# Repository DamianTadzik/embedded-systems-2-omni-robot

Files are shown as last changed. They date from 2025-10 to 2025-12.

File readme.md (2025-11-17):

Hello this is repo for laboratories

Embedded Systems 2 na upelu - ES2_2025

## Project Overview
The project is divided into several software layers, each with a well-defined interface.  
Main goals:
- Controlling the robot via a wireless controller.
- Training a neural network to detect specific objects (in this project: a can of Monster).
- Creating a program that makes the robot drive to a certain object and keep a desired distance.
- Designing and 3D printing accessories (camera station, battery station).

---

## Software Architecture

### L1 — Motion Control Layer
The main task of this layer is controlling the robot via signals directed to the wheels.  
- Receives the control vector **[Vx Vy ω]**, where:
  - Vx, Vy are linear velocities in m/s
  - ω is the angular velocity in rad/s
- This layer runs in a loop. If there is no message on the MQTT topic, the motors are stopped.
- Listens to MQTT topic for control commands.

---

### L2 — Control and Integration Layer
Layer 2 connects Layer 1 and Layer 3.  
- Implements the PID controller to control the robot’s speed and angle of its path.
- Maintains the robot at the desired distance from the object.
- Passes processed control signals to L1.

---

### L3 — Perception Layer
This layer implements the neural network (YOLO) to detect cans.  
- The Hisense camera used in the project provides depth calculation, which is passed to L2.
- The dataset consists of both self-collected and external images:
  - 30 self-collected and annotated images.
  - Additional images sourced from the internet and re-annotated to match labeling standards.

Dataset link: [Monster Net on Roboflow](https://universe.roboflow.com/monster-nzhgs/monster_net-e7vd2)

---

## System Flow
1. Neural network detects the can and outputs position and distance (L3)  
2. PID controller processes this data (L2)  
3. Control vector [Vx Vy ω] is sent to the robot motors (L1)  
4. Robot moves toward the object and maintains distance

---

## Hardware and Accessories
- 3D printed camera station
- 3D printed battery station
- Designed to improve stability and functionality of the robot

---

## Task Allocation

| Name | Responsibility | Layer |
|---|---|---|
| Damian Brzana | L1, remote controller, system architecture, LL Arduino driver | L1 |
| Oskar Brandys | L2 | L2 |
| Janusz Pawlicki | accessories, neural network | L3 |
| Adrian Paś | accessories, L2 | L2 |
| Stanisław Olech | neural network | L3 |

---

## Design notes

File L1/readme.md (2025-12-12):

# L1 – High-Level Velocity & Wheel Speed Control

The **L1 layer** is responsible for closing the **wheel speed control loop** on the host computer (Jetson/PC).
It receives high-level velocity commands `(vx, vy, omega)`, converts them into **desired wheel angular speeds**, and **regulates each wheel using PID controllers** based on encoder feedback from the LL (Arduino) layer.

L1 therefore no longer operates in open-loop PWM mode – **wheel speed control is closed in L1**.

---

## Responsibilities of L1

* Receive high-level velocity commands `(vx, vy, omega)` via MQTT
* Compute desired wheel angular velocities using mecanum inverse kinematics
* Read encoder feedback from LL over UART
* Compute wheel angular speeds `[rad/s]`
* Run **4 independent PID controllers** (one per wheel)
* Send **PWM duty cycles** to LL

---

## Control Architecture

```
(vx, vy, omega)
        ↓
   Inverse Kinematics
        ↓
Desired wheel speeds [rad/s]
        ↓
   PID (per wheel)
        ↓
   PWM duty cycles
        ↓
        LL (Arduino)
        ↓
     Motors + Encoders
        ↑
   Encoder feedback (UART)
```

---

## Project Structure

```
L1.py              # Main control loop (IK + PID + UART)
PID.py             # Simple PID controller implementation
kinematics.py      # Mecanum inverse kinematics
serial_link.py     # UART protocol + encoder decoding
mqtt_client.py     # MQTT interface (cmd_vel)
app.html           # Web joystick (debug / teleop)
TODO.md            # Planned improvements
```

---

## MQTT Interface

### Topic

```
robot/cmd_vel
```

### Message format

```json
{ "vx": 0.0, "vy": 0.0, "omega": 0.0 }
```

* `vx`, `vy` – linear velocities [m/s]
* `omega` – angular velocity [rad/s]

Commands may originate from:

* **L2 motion planner** (normal operation)
* **Web UI** (`app.html`) for testing

---

## UART Interface (L1 ↔ LL)

### L1 → LL

* Sends PWM duty cycles for 4 wheels
* Range: `[-127, 127]` (mapped internally to signed percentage)

### LL → L1

* Sends raw encoder counts (16-bit, with wrap-around)
* L1 computes:

  * wheel angular speed `[rad/s]`
  * loop `dt`

All encoder handling and speed estimation is done in **serial_link.py**.

---

## PID Control

* One PID per wheel: `TL`, `TR`, `BL`, `BR`
* Inputs:

  * Target wheel speed `[rad/s]`
  * Measured wheel speed `[rad/s]`
* Output:

  * PWM duty cycle command

Current gains (to be tuned):

```
kp = 1.2
ki = 12.0
kd = 0.04
output_limit = 127
```

---

## Web Controller (Debug Only)

`app.html` provides:

* Virtual joystick → `(vx, vy)`
* Slider → `omega`
* MQTT over WebSockets

Used **only for debugging and teleoperation** when L2 is unavailable.

---

## How to Run

### 1. Start MQTT broker

```
mosquitto -v -c my_mosquitto.conf
```

### 2. Run L1

```
python3 L1.py
```

Dependencies:

```
pip install paho-mqtt pyserial numpy
```

L1 will:

* Connect to MQTT (`localhost:1883`)
* Open `/dev/ttyACM0`
* Start encoder reader thread
* Close the wheel speed control loop

---

## Data Flow Summary

```
L2 / Web UI
      ↓ MQTT
     L1 (IK + PID)
      ↓ UART
     LL (Motor driver)
      ↓
    Motors
```

---

## Notes

* L1 is now a **real-time wheel speed regulator**, not just a kinematics bridge
* LL firmware is simplified (no PID inside Arduino)
* Timing quality depends on host OS scheduling
* Future improvement: move PID to LL if hard real-time is required

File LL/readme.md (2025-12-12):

# LL – Low-Level Motor & Encoder Interface

The **LL layer** runs on the Arduino and acts as a **pure hardware interface**.
It applies motor commands and reports encoder data. **No control logic is implemented here.**

---

## Responsibilities

* Receive PWM duty cycle commands from L1 over UART
* Drive motor direction and PWM outputs
* Read quadrature encoders
* Send **raw 16-bit encoder counts** back to L1

---

## Explicitly NOT in LL

* No PID or control loops
* No kinematics
* No velocity regulation
* No decision logic

All control is handled in **L1**.

---

## UART Interface

### L1 → LL (Motor command frame)

```
[START][TL][TR][BL][BR][CHECKSUM]
```

* Signed values encode direction and duty cycle

### LL → L1 (Encoder frame)

```
[START][TL_lo][TL_hi][TR_lo][TR_hi][BL_lo][BL_hi][BR_lo][BR_hi][CHECKSUM]
```

* 16-bit encoder counts
* Wrap-around handled in L1

---

## Timing

* LL runs as fast as possible
* No blocking delays
* Control timing is dictated by L1

---

## Notes

LL is intentionally minimal. If behavior is incorrect, the issue is almost certainly in **L1**, not LL.

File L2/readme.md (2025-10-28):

L2- Second layer

Responsible for controling velocities of the robot's frame of reference based on the distance from detected object from the robot and on location of it's center in the frame.

INPUTS:

&nbsp;	- Distance from the detected object (distance)

&nbsp;	- Location of center of detected object in the frame (C(x,y))

OUTPUTS:

&nbsp;	- vx - translational velocity along x axis of robot's reference frame

&nbsp;	- vy - translational velocity along y axis of robot's reference frame

&nbsp;	- omega - rotational velocity along z axis of robot's reference frame

Script consists of angle and distance regulators (which are implemented, based on choice, with two-state position controllers or PID controllers), which operate on angle and distance variables. Both are calculated with help of inputs and knwoledge of camera's FOV.

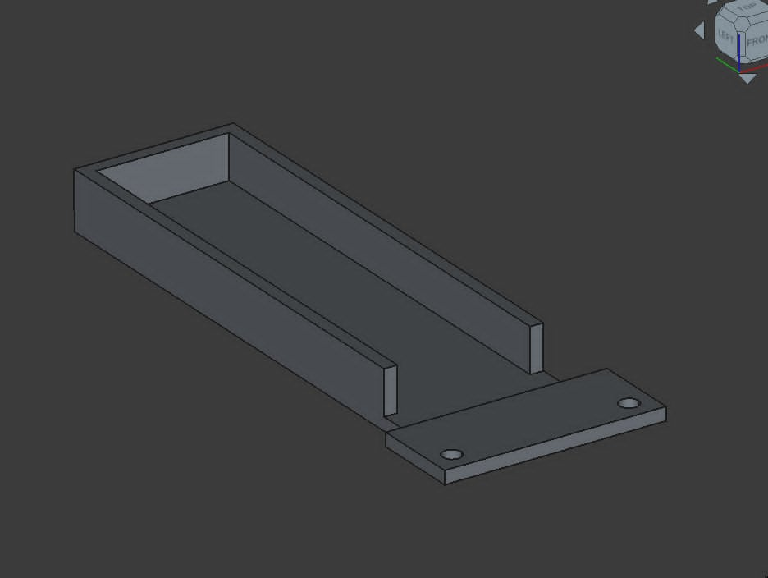
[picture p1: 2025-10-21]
Hardware/bateria.jpg

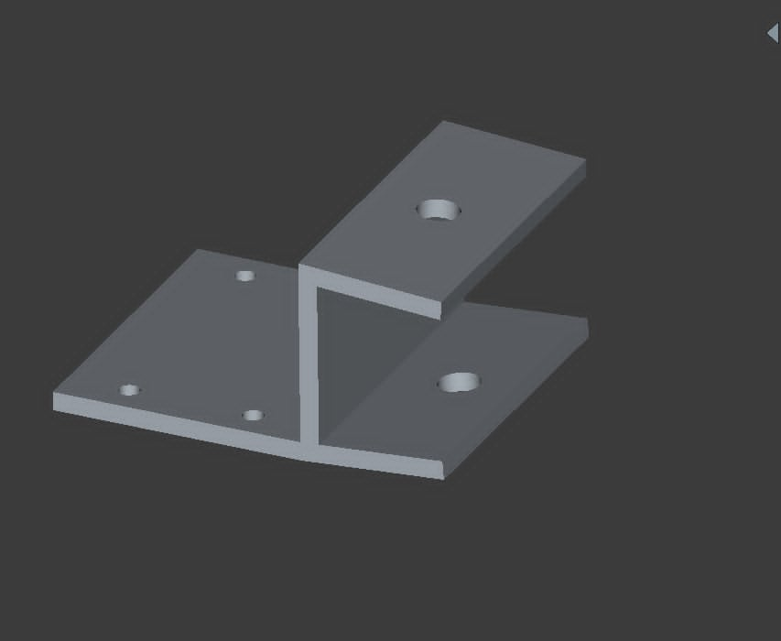
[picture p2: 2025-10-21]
Hardware/kamera.jpg

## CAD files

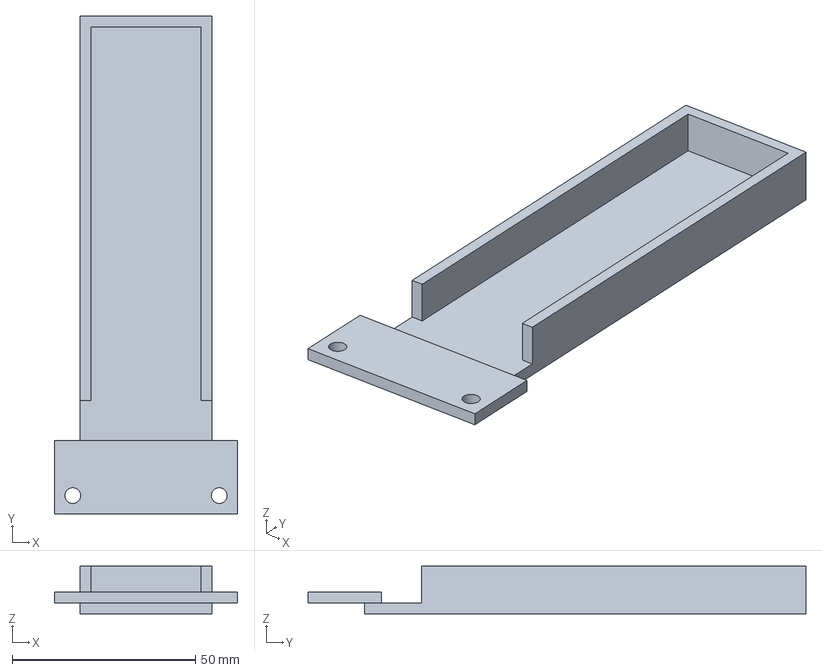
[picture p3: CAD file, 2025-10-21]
Hardware/trzymacz_baterii.FCStd
50.0 x 136.0 x 13.0 mm

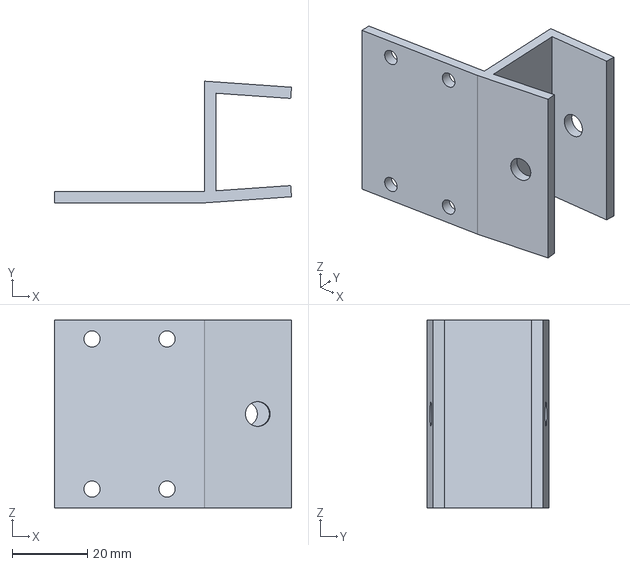
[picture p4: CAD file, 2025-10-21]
Hardware/uchwyt_na_kamere.FCStd
63.2 x 32.4 x 50.0 mm

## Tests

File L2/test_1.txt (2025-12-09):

est_angle: 0.0est_dist: 0.3speeds: 0,0detection_flag: Falseraw_angle: Noneest_angle: 0.0est_dist: 0.3speeds: 0,0detection_flag: Falseraw_angle: Noneest_angle: 0.0est_dist: 0.3speeds: 0,0detection_flag: Falseraw_angle: Noneraw_dist: None
est_angle: 0.0est_dist: 0.3speeds: 0,0detection_flag: Falseraw_angle: Noneraw_dist: None
est_angle: 0.0est_dist: 0.3speeds: 0,0detection_flag: Falseraw_angle: Noneraw_dist: None
est_angle: 0.0est_dist: 0.3speeds: 0,0detection_flag: Falseraw_angle: Noneraw_dist: None
est_angle: 0.0est_dist: 0.3speeds: 0,0detection_flag: Falseraw_angle: Noneraw_dist: None
est_angle: 0.0est_dist: 0.3speeds: 0,0detection_flag: Falseraw_angle: Noneraw_dist: None
est_angle: 0.0est_dist: 0.3speeds: 0,0detection_flag: Falseraw_angle: Noneraw_dist: None
est_angle: 0.0est_dist: 0.3speeds: 0,0detection_flag: Falseraw_angle: Noneraw_dist: None
est_angle: 0.0est_dist: 0.3speeds: 0,0detection_flag: Falseraw_angle: Noneraw_dist: None
est_angle: 0.0est_dist: 0.3speeds: 0,0detection_flag: Falseraw_angle: Noneraw_dist: None
est_angle: 0.0est_dist: 0.3speeds: 0,0detection_flag: Falseraw_angle: Noneraw_dist: None
est_angle: 0.0est_dist: 0.3speeds: 0,0detection_flag: Falseraw_angle: Noneraw_dist: None
est_angle: 0.0est_dist: 0.3speeds: 0,0detection_flag: Falseraw_angle: Noneraw_dist: None
est_angle: 0.0est_dist: 0.3speeds: 0,0detection_flag: Falseraw_angle: Noneraw_dist: None
est_angle: 0.0est_dist: 0.3speeds: 0,0detection_flag: Falseraw_angle: Noneraw_dist: None
est_angle: 0.0est_dist: 0.3speeds: 0,0detection_flag: Falseraw_angle: Noneraw_dist: None
est_angle: 0.0est_dist: 0.3speeds: 0,0detection_flag: Falseraw_angle: Noneraw_dist: None
est_angle: 0.0est_dist: 0.3speeds: 0,0detection_flag: Falseraw_angle: Noneraw_dist: None
est_angle: 0.0est_dist: 0.3speeds: 0,0detection_flag: Falseraw_angle: Noneraw_dist: None
est_angle: 0.0est_dist: 0.3speeds: 0,0detection_flag: Falseraw_angle: Noneraw_dist: None
est_angle: 0.0est_dist: 0.3speeds: 0,0detection_flag: Falseraw_angle: Noneraw_dist: None
est_angle: 0.0est_dist: 0.3speeds: 0,0detection_flag: Falseraw_angle: Noneraw_dist: None
est_angle: 0.0est_dist: 0.3speeds: 0,0detection_flag: Falseraw_angle: Noneraw_dist: None
est_angle: 0.0est_dist: 0.3speeds: 0,0detection_flag: Falseraw_angle: Noneraw_dist: None
est_angle: 0.0est_dist: 0.3speeds: 0,0detection_flag: Falseraw_angle: Noneraw_dist: None
est_angle: 0.0est_dist: 0.3speeds: 0,0detection_flag: Falseraw_angle: Noneraw_dist: None
est_angle: 0.0est_dist: 0.3speeds: 0,0detection_flag: Falseraw_angle: Noneraw_dist: None
est_angle: 0.0est_dist: 0.3speeds: 0,0detection_flag: Falseraw_angle: Noneraw_dist: None
est_angle: 0.0est_dist: 0.3speeds: 0,0detection_flag: Falseraw_angle: Noneraw_dist: None
est_angle: 0.0est_dist: 0.3speeds: 0,0detection_flag: Falseraw_angle: Noneraw_dist: None
est_angle: 0.0est_dist: 0.3speeds: 0,0detection_flag: Falseraw_angle: Noneraw_dist: None
est_angle: 0.0est_dist: 0.3speeds: 0,0detection_flag: Falseraw_angle: Noneraw_dist: None
est_angle: 0.0est_dist: 0.3speeds: 0,0detection_flag: Falseraw_angle: Noneraw_dist: None
est_angle: 0.0est_dist: 0.3speeds: 0,0detection_flag: Falseraw_angle: Noneraw_dist: None
est_angle: 0.0est_dist: 0.3speeds: 0,0detection_flag: Falseraw_angle: Noneraw_dist: None
est_angle: 0.0est_dist: 0.3speeds: 0,0detection_flag: Falseraw_angle: Noneraw_dist: None
est_angle: 0.0est_dist: 0.3speeds: 0,0detection_flag: Falseraw_angle: Noneraw_dist: None
est_angle: 0.0est_dist: 0.3speeds: 0,0detection_flag: Falseraw_angle: Noneraw_dist: None
est_angle: 0.0est_dist: 0.3speeds: 0,0detection_flag: Falseraw_angle: Noneraw_dist: None
est_angle: 0.0est_dist: 0.3speeds: 0,0detection_flag: Falseraw_angle: Noneraw_dist: None
est_angle: 0.0est_dist: 0.3speeds: 0,0detection_flag: Falseraw_angle: Noneraw_dist: None
est_angle: 0.0est_dist: 0.3speeds: 0,0detection_flag: Falseraw_angle: Noneraw_dist: None
est_angle: 0.0est_dist: 0.3speeds: 0,0detection_flag: Falseraw_angle: Noneraw_dist: None
est_angle: 0.0est_dist: 0.3speeds: 0,0detection_flag: Falseraw_angle: Noneraw_dist: None
est_angle: 0.0est_dist: 0.3speeds: 0,0detection_flag: Falseraw_angle: Noneraw_dist: None
est_angle: 0.0est_dist: 0.3speeds: 0,0detection_flag: Falseraw_angle: Noneraw_dist: None
est_angle: 0.0est_dist: 0.3speeds: 0,0detection_flag: Falseraw_angle: Noneraw_dist: None
est_angle: 0.0est_dist: 0.3speeds: 0,0detection_flag: Falseraw_angle: Noneraw_dist: None
est_angle: 0.0est_dist: 0.3speeds: 0,0detection_flag: Falseraw_angle: Noneraw_dist: None
est_angle: 0.0est_dist: 0.3speeds: 0,0detection_flag: Falseraw_angle: Noneraw_dist: None
est_angle: 0.0est_dist: 0.3speeds: 0,0detection_flag: Falseraw_angle: Noneraw_dist: None
est_angle: 0.0est_dist: 0.3speeds: 0,0detection_flag: Falseraw_angle: Noneraw_dist: None
est_angle: 0.0est_dist: 0.3speeds: 0,0detection_flag: Falseraw_angle: Noneraw_dist: None
est_angle: 0.0est_dist: 0.3speeds: 0,0detection_flag: Falseraw_angle: Noneraw_dist: None
est_angle: 0.0est_dist: 0.3speeds: 0,0detection_flag: Falseraw_angle: Noneraw_dist: None
est_angle: 0.0est_dist: 0.3speeds: 0,0detection_flag: Falseraw_angle: Noneraw_dist: None
est_angle: 0.0est_dist: 0.3speeds: 0,0detection_flag: Falseraw_angle: Noneraw_dist: None
est_angle: 0.0est_dist: 0.3speeds: 0,0detection_flag: Falseraw_angle: Noneraw_dist: None
est_angle: 0.0est_dist: 0.3speeds: 0,0detection_flag: Falseraw_angle: Noneraw_dist: None
est_angle: 0.0est_dist: 0.3speeds: 0,0detection_flag: Falseraw_angle: Noneraw_dist: None
est_angle: 0.0est_dist: 0.3speeds: 0,0detection_flag: Falseraw_angle: Noneraw_dist: None
est_angle: 0.0est_dist: 0.3speeds: 0,0detection_flag: Falseraw_angle: Noneraw_dist: None
est_angle: 0.0est_dist: 0.3speeds: 0,0detection_flag: Falseraw_angle: Noneraw_dist: None
est_angle: 0.0est_dist: 0.3speeds: 0,0detection_flag: Falseraw_angle: Noneraw_dist: None
est_angle: 0.0est_dist: 0.3speeds: 0,0detection_flag: Falseraw_angle: Noneraw_dist: None
est_angle: 0.0est_dist: 0.3speeds: 0,0detection_flag: Falseraw_angle: Noneraw_dist: None
est_angle: 0.0est_dist: 0.3speeds: 0,0detection_flag: Falseraw_angle: Noneraw_dist: None
est_angle: 0.0est_dist: 0.3speeds: 0,0detection_flag: Falseraw_angle: Noneraw_dist: None
est_angle: 0.0est_dist: 0.3speeds: 0,0detection_flag: Falseraw_angle: Noneraw_dist: None
est_angle: 0.0est_dist: 0.3speeds: 0,0detection_flag: Falseraw_angle: Noneraw_dist: None
est_angle: 0.0est_dist: 0.3speeds: 0,0detection_flag: Falseraw_angle: Noneraw_dist: None
est_angle: 0.0est_dist: 0.3speeds: 0,0detection_flag: Falseraw_angle: Noneraw_dist: None
est_angle: 0.0est_dist: 0.3speeds: 0,0detection_flag: Falseraw_angle: Noneraw_dist: None
est_angle: 0.0est_dist: 0.3speeds: 0,0detection_flag: Falseraw_angle: Noneraw_dist: None
est_angle: 0.0est_dist: 0.3speeds: 0,0detection_flag: Falseraw_angle: Noneraw_dist: None
est_angle: 0.0est_dist: 0.3speeds: 0,0detection_flag: Falseraw_angle: Noneraw_dist: None
est_angle: 0.0est_dist: 0.3speeds: 0,0detection_flag: Falseraw_angle: Noneraw_dist: None
est_angle: 0.0est_dist: 0.3speeds: 0,0detection_flag: Falseraw_angle: Noneraw_dist: None
est_angle: 0.0est_dist: 0.3speeds: 0,0detection_flag: Falseraw_angle: Noneraw_dist: None
est_angle: 0.0est_dist: 0.3speeds: 0,0detection_flag: Falseraw_angle: Noneraw_dist: None
est_angle: 0.0est_dist: 0.3speeds: 0,0detection_flag: Falseraw_angle: Noneraw_dist: None
est_angle: 0.0est_dist: 0.3speeds: 0,0detection_flag: Falseraw_angle: Noneraw_dist: None
est_angle: 0.0est_dist: 0.3speeds: 0,0detection_flag: Falseraw_angle: Noneraw_dist: None
est_angle: 0.0est_dist: 0.3speeds: 0,0detection_flag: Falseraw_angle: Noneraw_dist: None
est_angle: 0.0est_dist: 0.3speeds: 0,0detection_flag: Falseraw_angle: Noneraw_dist: None
est_angle: 0.0est_dist: 0.3speeds: 0,0detection_flag: Falseraw_angle: Noneraw_dist: None
est_angle: 0.0est_dist: 0.3speeds: 0,0detection_flag: Falseraw_angle: Noneraw_dist: None
est_angle: 0.0est_dist: 0.3speeds: 0,0detection_flag: Falseraw_angle: Noneraw_dist: None
est_angle: 0.0est_dist: 0.3speeds: 0,0detection_flag: Falseraw_angle: Noneraw_dist: None
est_angle: 0.0est_dist: 0.3speeds: 0,0detection_flag: Falseraw_angle: Noneraw_dist: None
est_angle: 0.0est_dist: 0.3speeds: 0,0detection_flag: Falseraw_angle: Noneraw_dist: None
est_angle: 0.0est_dist: 0.3speeds: 0,0detection_flag: Falseraw_angle: Noneraw_dist: None
est_angle: 0.0est_dist: 0.3speeds: 0,0detection_flag: Falseraw_angle: Noneraw_dist: None
est_angle: 0.0est_dist: 0.3speeds: 0,0detection_flag: Falseraw_angle: Noneraw_dist: None
est_angle: 0.0est_dist: 0.3speeds: 0,0detection_flag: Falseraw_angle: Noneraw_dist: None
est_angle: 0.0est_dist: 0.3speeds: 0,0detection_flag: Falseraw_angle: Noneraw_dist: None
est_angle: 0.0est_dist: 0.3speeds: 0,0detection_flag: Falseraw_angle: Noneraw_dist: None
est_angle: 0.0est_dist: 0.3speeds: 0,0detection_flag: Falseraw_angle: Noneraw_dist: None
est_angle: 0.0est_dist: 0.3speeds: 0,0detection_flag: Falseraw_angle: Noneraw_dist: None
est_angle: 0.0est_dist: 0.3speeds: 0,0detection_flag: Trueraw_angle: Noneraw_dist: None
est_angle: 0.0est_dist: 0.3299961805343628speeds: 0.3,0.0detection_flag: Falseraw_angle: Noneraw_dist: None
est_angle: 0.0est_dist: 0.3630041069022809speeds: 0.3299961805343628,0.0detection_flag: Falseraw_angle: Noneraw_dist: None
est_angle: 0.0est_dist: 0.3680074638358747speeds: 0.05,0.0detection_flag: Falseraw_angle: Noneraw_dist: None
est_angle: 0.0est_dist: 0.3730068987838422speeds: 0.05,0.0detection_flag: Falseraw_angle: Noneraw_dist: None
est_angle: 0.0est_dist: 0.37800774040142643speeds: 0.05,0.0detection_flag: Trueraw_angle: Noneraw_dist: None
est_angle: 0.0est_dist: 0.38301033439556703speeds: 0.05,0.0detection_flag: Falseraw_angle: Noneraw_dist: None
est_angle: 0.0est_dist: 0.38801023425976383speeds: 0.05,0.0detection_flag: Falseraw_angle: Noneraw_dist: None
est_angle: 0.0est_dist: 0.39301180305401434speeds: 0.05,0.0detection_flag: Falseraw_angle: Noneraw_dist: None
est_angle: 0.0est_dist: 0.3980129784576093speeds: 0.05,0.0detection_flag: Falseraw_angle: Noneraw_dist: None
est_angle: 0.0est_dist: 0.40301396312634097speeds: 0.05,0.0detection_flag: Falseraw_angle: Noneraw_dist: None
est_angle: 0.0est_dist: 0.4080159968368207speeds: 0.05,0.0detection_flag: Falseraw_angle: Noneraw_dist: None
est_angle: 0.0est_dist: 0.4130165285102521speeds: 0.05,0.0detection_flag: Falseraw_angle: Noneraw_dist: None
est_angle: 0.0est_dist: 0.4180184191695844speeds: 0.05,0.0detection_flag: Falseraw_angle: Noneraw_dist: None
est_angle: 0.0est_dist: 0.42301829519192324speeds: 0.05,0.0detection_flag: Trueraw_angle: Noneraw_dist: None
est_angle: 0.0est_dist: 0.42801850500027283speeds: 0.05,0.0detection_flag: Falseraw_angle: Noneraw_dist: None
est_angle: 0.0est_dist: 0.43301983537594424speeds: 0.05,0.0detection_flag: Falseraw_angle: Noneraw_dist: None
est_angle: 0.0est_dist: 0.4380209034911786speeds: 0.05,0.0detection_flag: Falseraw_angle: Noneraw_dist: None
est_angle: 0.0est_dist: 0.4430216258994733speeds: 0.05,0.0detection_flag: Falseraw_angle: Noneraw_dist: None
est_angle: 0.0est_dist: 0.4480245179168378speeds: 0.05,0.0detection_flag: Falseraw_angle: Noneraw_dist: None
est_angle: 0.0est_dist: 0.4530239290229474speeds: 0.05,0.0detection_flag: Falseraw_angle: Noneraw_dist: None
est_angle: 0.0est_dist: 0.45802496137539495speeds: 0.05,0.0detection_flag: Falseraw_angle: Noneraw_dist: None
est_angle: 0.0est_dist: 0.46302591028133977speeds: 0.05,0.0detection_flag: Falseraw_angle: Noneraw_dist: None
est_angle: 0.0est_dist: 0.4680267757407819speeds: 0.05,0.0detection_flag: Trueraw_angle: Noneraw_dist: None
est_angle: 0.0est_dist: 0.47302789153973207speeds: 0.05,0.0detection_flag: Falseraw_angle: Noneraw_dist: None
est_angle: 0.0est_dist: 0.4780290192596112speeds: 0.05,0.0detection_flag: Falseraw_angle: Noneraw_dist: None
est_angle: 0.0est_dist: 0.48303152980724917speeds: 0.05,0.0detection_flag: Falseraw_angle: Noneraw_dist: None
est_angle: 0.0est_dist: 0.4880309885970746speeds: 0.05,0.0detection_flag: Falseraw_angle: Noneraw_dist: None
est_angle: 0.0est_dist: 0.493032056712309speeds: 0.05,0.0detection_flag: Falseraw_angle: Noneraw_dist: None
est_angle: 0.0est_dist: 0.4980329221717511speeds: 0.05,0.0detection_flag: Falseraw_angle: Noneraw_dist: None
est_angle: 0.0est_dist: 0.5030336445800457speeds: 0.05,0.0detection_flag: Falseraw_angle: Noneraw_dist: None
est_angle: 0.0est_dist: 0.5080350822440777speeds: 0.05,0.0detection_flag: Falseraw_angle: Noneraw_dist: None
est_angle: 0.0est_dist: 0.5130349821082745speeds: 0.05,0.0detection_flag: Trueraw_angle: Noneraw_dist: None
est_angle: 0.0est_dist: 0.5180367535583172speeds: 0.05,0.0detection_flag: Falseraw_angle: Noneraw_dist: None
est_angle: 0.0est_dist: 0.5230373329154645speeds: 0.05,0.0detection_flag: Falseraw_angle: Noneraw_dist: None
est_angle: 0.0est_dist: 0.5280379957191144speeds: 0.05,0.0detection_flag: Falseraw_angle: Noneraw_dist: None
est_angle: 0.0est_dist: 0.5330392307273542speeds: 0.05,0.0detection_flag: Falseraw_angle: Noneraw_dist: None
est_angle: 0.0est_dist: 0.5380401319495831speeds: 0.05,0.0detection_flag: Falseraw_angle: Noneraw_dist: None
est_angle: 0.0est_dist: 0.5430424398414289speeds: 0.05,0.0detection_flag: Falseraw_angle: Noneraw_dist: None
est_angle: 0.0est_dist: 0.5480425781242048speeds: 0.05,0.0detection_flag: Falseraw_angle: Noneraw_dist: None
est_angle: 0.0est_dist: 0.5530432766906416speeds: 0.05,0.0detection_flag: Falseraw_angle: Noneraw_dist: None
est_angle: 0.0est_dist: 0.5580442613593732speeds: 0.05,0.0detection_flag: Falseraw_angle: Noneraw_dist: None
est_angle: 0.0est_dist: 0.5630447453490888speeds: 0.05,0.0detection_flag: Trueraw_angle: Noneraw_dist: None
est_angle: 0.0est_dist: 0.5680453723899518speeds: 0.05,0.0detection_flag: Falseraw_angle: Noneraw_dist: None
est_angle: 0.0est_dist: 0.5730460351936016speeds: 0.05,0.0detection_flag: Falseraw_angle: Noneraw_dist: None
est_angle: 0.0est_dist: 0.5780467933646832speeds: 0.05,0.0detection_flag: Falseraw_angle: Noneraw_dist: None
est_angle: 0.0est_dist: 0.5830476230613385speeds: 0.05,0.0detection_flag: Falseraw_angle: Noneraw_dist: None
est_angle: 0.0est_dist: 0.5880482024184858speeds: 0.05,0.0detection_flag: Falseraw_angle: Noneraw_dist: None
est_angle: 0.0est_dist: 0.5930486029616987speeds: 0.05,0.0detection_flag: Falseraw_angle: Noneraw_dist: None
est_angle: 0.0est_dist: 0.5980495041839277speeds: 0.05,0.0detection_flag: Falseraw_angle: Noneraw_dist: None
est_angle: 0.0est_dist: 0.6030502027503645speeds: 0.05,0.0detection_flag: Falseraw_angle: Noneraw_dist: None
est_angle: 0.0est_dist: 0.6080513662330305speeds: 0.05,0.0detection_flag: Trueraw_angle: Noneraw_dist: None
est_angle: 0.0est_dist: 0.6130523389808332speeds: 0.05,0.0detection_flag: Falseraw_angle: Noneraw_dist: None
est_angle: 0.0est_dist: 0.6180546826354658speeds: 0.05,0.0detection_flag: Falseraw_angle: Noneraw_dist: None
est_angle: 0.0est_dist: 0.623053426169554speeds: 0.05,0.0detection_flag: Falseraw_angle: Noneraw_dist: None
est_angle: 0.0est_dist: 0.6280537909499799speeds: 0.05,0.0detection_flag: Falseraw_angle: Noneraw_dist: None
est_angle: 0.0est_dist: 0.6330545848838484speeds: 0.05,0.0detection_flag: Falseraw_angle: Noneraw_dist: None
est_angle: 0.0est_dist: 0.6380568331710493speeds: 0.05,0.0detection_flag: Falseraw_angle: Noneraw_dist: None
est_angle: 0.0est_dist: 0.6430568045608198speeds: 0.05,0.0detection_flag: Falseraw_angle: Noneraw_dist: None
est_angle: 0.0est_dist: 0.648057681941191speeds: 0.05,0.0detection_flag: Falseraw_angle: Noneraw_dist: None
est_angle: 0.0est_dist: 0.6530577010146773speeds: 0.05,0.0detection_flag: Trueraw_angle: Noneraw_dist: None
est_angle: 0.0est_dist: 0.6580583518973983speeds: 0.05,0.0detection_flag: Falseraw_angle: Noneraw_dist: None
est_angle: 0.0est_dist: 0.6630593842498458speeds: 0.05,0.0detection_flag: Falseraw_angle: Noneraw_dist: None
est_angle: 0.0est_dist: 0.6680612391463912speeds: 0.05,0.0detection_flag: Falseraw_angle: Noneraw_dist: None
est_angle: 0.0est_dist: 0.6730602926246321speeds: 0.05,0.0detection_flag: Falseraw_angle: Noneraw_dist: None
est_angle: 0.0est_dist: 0.6780612772933637speeds: 0.05,0.0detection_flag: Falseraw_angle: Noneraw_dist: None
est_angle: 0.0est_dist: 0.6830619043342268speeds: 0.05,0.0detection_flag: Falseraw_angle: Noneraw_dist: None
est_angle: 0.0est_dist: 0.688062483691374speeds: 0.05,0.0detection_flag: Falseraw_angle: Noneraw_dist: None
est_angle: 0.0est_dist: 0.693063921355406speeds: 0.05,0.0detection_flag: Falseraw_angle: Noneraw_dist: None
est_angle: 0.0est_dist: 0.6980651802055036speeds: 0.05,0.0detection_flag: Falseraw_angle: Noneraw_dist: None
est_angle: 0.0est_dist: 0.7030660814277325speeds: 0.05,0.0detection_flag: Trueraw_angle: Noneraw_dist: None
est_angle: 0.0est_dist: 0.7080672449103985speeds: 0.05,0.0detection_flag: Falseraw_angle: Noneraw_dist: None
est_angle: 0.0est_dist: 0.7130684918395672speeds: 0.05,0.0detection_flag: Falseraw_angle: Noneraw_dist: None
est_angle: 0.0est_dist: 0.7180688566199932speeds: 0.05,0.0detection_flag: Falseraw_angle: Noneraw_dist: None
est_angle: 0.0est_dist: 0.7230711764327679speeds: 0.05,0.0detection_flag: Falseraw_angle: Noneraw_dist: None
est_angle: 0.0est_dist: 0.7280720061294231speeds: 0.05,0.0detection_flag: Falseraw_angle: Noneraw_dist: None
est_angle: 0.0est_dist: 0.7330717629424724speeds: 0.05,0.0detection_flag: Falseraw_angle: Noneraw_dist: None
est_angle: 0.0est_dist: 0.7380729025832805speeds: 0.05,0.0detection_flag: Falseraw_angle: Noneraw_dist: None
est_angle: 0.0est_dist: 0.7430760091773662speeds: 0.05,0.0detection_flag: Falseraw_angle: Noneraw_dist: None
est_angle: 0.0est_dist: 0.7480761116973552speeds: 0.05,0.0detection_flag: Trueraw_angle: Noneraw_dist: None
est_angle: 0.0est_dist: 0.7530770248405132speeds: 0.05,0.0detection_flag: Falseraw_angle: Noneraw_dist: None
est_angle: 0.0est_dist: 0.7580783075324687speeds: 0.05,0.0detection_flag: Falseraw_angle: Noneraw_dist: None
est_angle: 0.0est_dist: 0.7630793279639873speeds: 0.05,0.0detection_flag: Falseraw_angle: Noneraw_dist: None
est_angle: 0.0est_dist: 0.768080837153593speeds: 0.05,0.0detection_flag: Falseraw_angle: Noneraw_dist: None
est_angle: 0.0est_dist: 0.7730816310874614speeds: 0.05,0.0detection_flag: Falseraw_angle: Noneraw_dist: None
est_angle: 0.0est_dist: 0.778082663439909speeds: 0.05,0.0detection_flag: Falseraw_angle: Noneraw_dist: None
est_angle: 0.0est_dist: 0.7830835765830669speeds: 0.05,0.0detection_flag: Falseraw_angle: Noneraw_dist: None
est_angle: 0.0est_dist: 0.7880849665633831speeds: 0.05,0.0detection_flag: Falseraw_angle: Noneraw_dist: None
est_angle: 0.0est_dist: 0.7930857962600384speeds: 0.05,0.0detection_flag: Trueraw_angle: Noneraw_dist: None
est_angle: 0.0est_dist: 0.7980863517753277speeds: 0.05,0.0detection_flag: Falseraw_angle: Noneraw_dist: None
est_angle: 0.0est_dist: 0.8030869549743328speeds: 0.05,0.0detection_flag: Falseraw_angle: Noneraw_dist: None
est_angle: 0.0est_dist: 0.8080877727500592speeds: 0.05,0.0detection_flag: Falseraw_angle: Noneraw_dist: None
est_angle: 0.0est_dist: 0.8130890792838726speeds: 0.05,0.0detection_flag: Falseraw_angle: Noneraw_dist: None
est_angle: 0.0est_dist: 0.818089861296812speeds: 0.05,0.0detection_flag: Falseraw_angle: Noneraw_dist: None
est_angle: 0.0est_dist: 0.8230909770957623speeds: 0.05,0.0detection_flag: Falseraw_angle: Noneraw_dist: None
est_angle: 0.0est_dist: 0.828092486285368speeds: 0.05,0.0detection_flag: Falseraw_angle: Noneraw_dist: None
est_angle: 0.0est_dist: 0.833103997134367speeds: 0.05,0.0detection_flag: Falseraw_angle: Noneraw_dist: None
est_angle: 0.0est_dist: 0.8381055182449016speeds: 0.05,0.0detection_flag: Falseraw_angle: Noneraw_dist: None
est_angle: 0.0est_dist: 0.8431065267554912speeds: 0.05,0.0detection_flag: Falseraw_angle: Noneraw_dist: None
est_angle: 0.0est_dist: 0.8481074160567913speeds: 0.05,0.0detection_flag: Falseraw_angle: Noneraw_dist: None
est_angle: 0.0est_dist: 0.8531087106696759speeds: 0.05,0.0detection_flag: Falseraw_angle: Noneraw_dist: None
est_angle: 0.0est_dist: 0.8581096476546918speeds: 0.05,0.0detection_flag: Falseraw_angle: Noneraw_dist: None
est_angle: 0.0est_dist: 0.8631108349792157speeds: 0.05,0.0detection_flag: Falseraw_angle: Noneraw_dist: None
est_angle: 0.0est_dist: 0.8681122249595319speeds: 0.05,0.0detection_flag: Falseraw_angle: Noneraw_dist: None
est_angle: 0.0est_dist: 0.8731126851073896speeds: 0.05,0.0detection_flag: Trueraw_angle: Noneraw_dist: None
est_angle: 0.0est_dist: 0.8781152671806013speeds: 0.05,0.0detection_flag: Trueraw_angle: Noneraw_dist: None
est_angle: 0.0est_dist: 0.88311571540753speeds: 0.05,0.0detection_flag: Falseraw_angle: Noneraw_dist: None
est_angle: 0.0est_dist: 0.8881165689460432speeds: 0.05,0.0detection_flag: Falseraw_angle: Noneraw_dist: None
est_angle: 0.0est_dist: 0.8931176609031355speeds: 0.05,0.0detection_flag: Falseraw_angle: Noneraw_dist: None
est_angle: 0.0est_dist: 0.8981187886230146speeds: 0.05,0.0detection_flag: Falseraw_angle: Noneraw_dist: None
est_angle: 0.0est_dist: 0.9031198090545332speeds: 0.05,0.0detection_flag: Falseraw_angle: Noneraw_dist: None
est_angle: 0.0est_dist: 0.908120757960478speeds: 0.05,0.0detection_flag: Falseraw_angle: Noneraw_dist: None
est_angle: 0.0est_dist: 0.9131220048896467speeds: 0.05,0.0detection_flag: Falseraw_angle: Noneraw_dist: None
est_angle: 0.0est_dist: 0.9181227392188703speeds: 0.05,0.0detection_flag: Falseraw_angle: Noneraw_dist: None
est_angle: 0.0est_dist: 0.9231229728690779speeds: 0.05,0.0detection_flag: Trueraw_angle: Noneraw_dist: None
est_angle: 0.0est_dist: 0.9281245178214704speeds: 0.05,0.0detection_flag: Falseraw_angle: Noneraw_dist: None
est_angle: 0.0est_dist: 0.9331255978576337speeds: 0.05,0.0detection_flag: Falseraw_angle: Noneraw_dist: None
est_angle: 0.0est_dist: 0.9381264990798627speeds: 0.05,0.0detection_flag: Falseraw_angle: Noneraw_dist: None
est_angle: 0.0est_dist: 0.943127328776518speeds: 0.05,0.0detection_flag: Falseraw_angle: Noneraw_dist: None
est_angle: 0.0est_dist: 0.948127931975523speeds: 0.05,0.0detection_flag: Falseraw_angle: Noneraw_dist: None
est_angle: 0.0est_dist: 0.9531286305419598speeds: 0.05,0.0detection_flag: Falseraw_angle: Noneraw_dist: None
est_angle: 0.0est_dist: 0.9581295436851178speeds: 0.05,0.0detection_flag: Falseraw_angle: Noneraw_dist: None
est_angle: 0.0est_dist: 0.9631303614608442speeds: 0.05,0.0detection_flag: Falseraw_angle: Noneraw_dist: None
est_angle: 0.0est_dist: 0.968132383250395speeds: 0.05,0.0detection_flag: Trueraw_angle: Noneraw_dist: None
est_angle: 0.0est_dist: 0.9731322473518049speeds: 0.05,0.0detection_flag: Falseraw_angle: Noneraw_dist: None
est_angle: 0.0est_dist: 0.9781330293647443speeds: 0.05,0.0detection_flag: Falseraw_angle: Noneraw_dist: None
est_angle: 0.0est_dist: 0.9831336325637494speeds: 0.05,0.0detection_flag: Falseraw_angle: Noneraw_dist: None
est_angle: 0.0est_dist: 0.988134354972044speeds: 0.05,0.0detection_flag: Falseraw_angle: Noneraw_dist: None
est_angle: 0.0est_dist: 0.9931349581710491speeds: 0.05,0.0detection_flag: Falseraw_angle: Noneraw_dist: None
est_angle: 0.0est_dist: 0.9981355971328412speeds: 0.05,0.0detection_flag: Falseraw_angle: Noneraw_dist: None
est_angle: 0.0est_dist: 1.0031361526481304speeds: 0.05,0.0detection_flag: Falseraw_angle: Noneraw_dist: None
est_angle: 0.0est_dist: 1.008136875056425speeds: 0.05,0.0detection_flag: Falseraw_angle: Noneraw_dist: None
est_angle: 0.0est_dist: 1.0131376213065777speeds: 0.05,0.0detection_flag: Trueraw_angle: Noneraw_dist: None
est_angle: 0.0est_dist: 1.0181382602683697speeds: 0.05,0.0detection_flag: Falseraw_angle: Noneraw_dist: None
est_angle: 0.0est_dist: 1.0231389945975933speeds: 0.05,0.0detection_flag: Falseraw_angle: Noneraw_dist: None
est_angle: 0.0est_dist: 1.0281395977965984speeds: 0.05,0.0detection_flag: Falseraw_angle: Noneraw_dist: None
est_angle: 0.0est_dist: 1.0331404155723247speeds: 0.05,0.0detection_flag: Falseraw_angle: Noneraw_dist: None
est_angle: 0.0est_dist: 1.038140983008543speeds: 0.05,0.0detection_flag: Falseraw_angle: Noneraw_dist: None
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

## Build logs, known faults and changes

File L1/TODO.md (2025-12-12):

After recieving telemetry from UART, post it over mqtt or idk
Add telemetry display to the webpage

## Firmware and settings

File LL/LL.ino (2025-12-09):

#include <Arduino.h>

// === Definicje pinów ===
const int pinDirTL = 15, pinPwmTL = 5, pinEncATL = 2, pinEncBTL = 18;
const int pinDirTR = 11, pinPwmTR = 10, pinEncATR = 12, pinEncBTR = 21;
const int pinDirBL = 19, pinPwmBL = 3, pinEncABL = 4, pinEncBBL = 8;
const int pinDirBR = 16, pinPwmBR = 9, pinEncABR = 6, pinEncBBR = 7;

// === Enkodery === // liczba impulsów na obrót enkodera: 240
volatile int32_t countTL = 0, countTR = 0, countBL = 0, countBR = 0;
void countPulseTL() { if (digitalRead(pinEncBTL)) countTL++; else countTL--; }
void countPulseTR() { if (digitalRead(pinEncBTR)) countTR++; else countTR--; }
void countPulseBL() { if (digitalRead(pinEncBBL)) countBL++; else countBL--; }
void countPulseBR() { if (digitalRead(pinEncBBR)) countBR++; else countBR--; }

// === Timeout guard ===
unsigned long lastCommand = 0;

void setup() {
  // Ustawienie pinów jako wyjścia
  pinMode(pinDirTL, OUTPUT);
  pinMode(pinPwmTL, OUTPUT);
  pinMode(pinDirTR, OUTPUT);
  pinMode(pinPwmTR, OUTPUT);
  pinMode(pinDirBL, OUTPUT);
  pinMode(pinPwmBL, OUTPUT);
  pinMode(pinDirBR, OUTPUT);
  pinMode(pinPwmBR, OUTPUT);
  // Ustawienie pinów enkoderów jako wejścia z podciąganiem
  pinMode(pinEncATL, INPUT_PULLUP);
  pinMode(pinEncBTL, INPUT_PULLUP);
  pinMode(pinEncATR, INPUT_PULLUP);
  pinMode(pinEncBTR, INPUT_PULLUP);
  pinMode(pinEncABL, INPUT_PULLUP);
  pinMode(pinEncBBL, INPUT_PULLUP);
  pinMode(pinEncABR, INPUT_PULLUP);
  pinMode(pinEncBBR, INPUT_PULLUP);
  // Ustawienie funkcji do obsługi przerwań dla enkoderów
  attachInterrupt(digitalPinToInterrupt(pinEncATL), countPulseTL, RISING);
  attachInterrupt(digitalPinToInterrupt(pinEncATR), countPulseTR, RISING);
  attachInterrupt(digitalPinToInterrupt(pinEncABL), countPulseBL, RISING);
  attachInterrupt(digitalPinToInterrupt(pinEncABR), countPulseBR, RISING);
  // Inicjalizacja komunikacji szeregowej
  Serial.begin(230400);
  lastCommand = millis();
}


// === Funkcja do sterowania silnikami ===
// TL/TR/BL/BR ∈ [-127, 127] → kierunek i PWM
// 0 = stop, 127 = pełna prędkość do przodu, -127 = pełna prędkość do tyłu 
void actuateMotors(int8_t TL, int8_t TR, int8_t BL, int8_t BR) {
  // --- TOP LEFT ---
  digitalWrite(pinDirTL, (TL >= 0) ? HIGH : LOW);
  analogWrite(pinPwmTL, abs(TL)<<1); // LSHFT skalowanie do [0, 254]

  // --- TOP RIGHT ---
  digitalWrite(pinDirTR, (TR >= 0) ? HIGH : LOW);
  analogWrite(pinPwmTR, abs(TR)<<1);

  // --- BOTTOM LEFT ---
  digitalWrite(pinDirBL, (BL >= 0) ? HIGH : LOW);
  analogWrite(pinPwmBL, abs(BL)<<1);

  // --- BOTTOM RIGHT ---
  digitalWrite(pinDirBR, (BR >= 0) ? HIGH : LOW);
  analogWrite(pinPwmBR, abs(BR)<<1);
}


bool readControlFrame(int8_t* wheelCmd) {
  // Sprawdzenie dostępności danych
  if (Serial.available() < 6) return false;
  
  // Odczyt nagłówka
  uint8_t header = Serial.read();
  if (header != 0xAA) return false;

  // Odczyt ramki
  uint8_t data[5] = {0};
  for (int i = 0; i < 5; i++) {
    data[i] = Serial.read();
  }

  // Kalkulacja sumy kontrolnej
  uint8_t checksum = 0xAA;
  for (int i = 0; i < 4; i++) {
    checksum += data[i];
  }

  // Sprawdzenie sumy kontrolnej
  if (checksum != 4[data]) return false;

  // Wypełnienie komend dla kół
  wheelCmd[0] = (int8_t)(data[0]); // TL
  wheelCmd[1] = (int8_t)(data[1]); // TR
  wheelCmd[2] = (int8_t)(data[2]); // BL
  wheelCmd[3] = (int8_t)(data[3]); // BR

  return true;
}

void sendEncodersFrame() {
  uint16_t tl, tr, bl, br;
  noInterrupts(); // Blokada przerwań podczas odczytu liczników
  tl = (uint16_t)(countTL & 0xFFFF);
  tr = (uint16_t)(countTR & 0xFFFF);
  bl = (uint16_t)(countBL & 0xFFFF);
  br = (uint16_t)(countBR & 0xFFFF);
  interrupts(); // Odblokowanie przerwań

  // Konstrukcja ramki
  uint8_t frame[10];
  frame[0] = 0xAA; // Nagłówek
  frame[1] = (uint8_t)(tl & 0xFF);
  frame[2] = (uint8_t)((tl >> 8) & 0xFF);
  frame[3] = (uint8_t)(tr & 0xFF);
  frame[4] = (uint8_t)((tr >> 8) & 0xFF);
  frame[5] = (uint8_t)(bl & 0xFF);
  frame[6] = (uint8_t)((bl >> 8) & 0xFF);
  frame[7] = (uint8_t)(br & 0xFF);
  frame[8] = (uint8_t)((br >> 8) & 0xFF);

  // Kalkulacja sumy kontrolnej
  uint8_t checksum = 0xAA;
  for (int i = 1; i <= 8; i++) {
    checksum += frame[i];
  }
  frame[9] = checksum & 0xFF;

  // Wysłanie ramki
  Serial.write(frame, 10);
}


void loop() {
  int8_t wheelCmd[4];

  if (readControlFrame(wheelCmd))
  {
    // Aktualizacja czasu ostatniej komendy
    lastCommand = millis(); 

    // Sterowanie silnikami
    actuateMotors(wheelCmd[0], wheelCmd[1], wheelCmd[2], wheelCmd[3]);

    // Wysłanie danych z enkoderów
    sendEncodersFrame();
  }

  // Safety stop if no command received for over 1 second
  if (millis() - lastCommand > 1000)
  {
    actuateMotors(0, 0, 0, 0); // Stop all motors
  }
}

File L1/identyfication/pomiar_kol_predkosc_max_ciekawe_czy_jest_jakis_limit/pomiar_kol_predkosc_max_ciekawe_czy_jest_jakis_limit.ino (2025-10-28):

#include <Arduino.h>

// --- Piny silników (z Twojego kodu) ---
const int pinDirTL = 15, pinPwmTL = 5;
const int pinDirTR = 11, pinPwmTR = 10;
const int pinDirBL = 19, pinPwmBL = 3;
const int pinDirBR = 16, pinPwmBR = 9;

// --- Piny enkoderów ---
const int pinEncATL = 2, pinEncBTL = 18;
const int pinEncATR = 12, pinEncBTR = 21;
const int pinEncABL = 4, pinEncBBL = 8;
const int pinEncABR = 6, pinEncBBR = 7;

// --- Liczniki impulsów ---
volatile long countTL = 0, countTR = 0, countBL = 0, countBR = 0;

// --- Przerwania enkoderów ---
void countPulseTL() { if (digitalRead(pinEncBTL)) countTL++; else countTL--; }
void countPulseTR() { if (digitalRead(pinEncBTR)) countTR++; else countTR--; }
void countPulseBL() { if (digitalRead(pinEncBBL)) countBL++; else countBL--; }
void countPulseBR() { if (digitalRead(pinEncBBR)) countBR++; else countBR--; }

// --- Konfiguracja pomiaru ---
const unsigned long sampleInterval = 20;  // ms
const int numSamples = 250;               // 5 sekund przy 100 Hz
unsigned long timeStamps[numSamples];
long dataTL[numSamples], dataTR[numSamples], dataBL[numSamples], dataBR[numSamples];

void setup() {
  Serial.begin(115200);
  delay(1000);

  // --- Ustawienia pinów silników ---
  pinMode(pinDirTL, OUTPUT); pinMode(pinPwmTL, OUTPUT);
  pinMode(pinDirTR, OUTPUT); pinMode(pinPwmTR, OUTPUT);
  pinMode(pinDirBL, OUTPUT); pinMode(pinPwmBL, OUTPUT);
  pinMode(pinDirBR, OUTPUT); pinMode(pinPwmBR, OUTPUT);

  // --- Kierunek jazdy (np. do przodu) ---
  digitalWrite(pinDirTL, HIGH);
  digitalWrite(pinDirTR, HIGH);
  digitalWrite(pinDirBL, HIGH);
  digitalWrite(pinDirBR, HIGH);

  // --- Enkodery ---
  pinMode(pinEncATL, INPUT_PULLUP); pinMode(pinEncBTL, INPUT_PULLUP);
  pinMode(pinEncATR, INPUT_PULLUP); pinMode(pinEncBTR, INPUT_PULLUP);
  pinMode(pinEncABL, INPUT_PULLUP); pinMode(pinEncBBL, INPUT_PULLUP);
  pinMode(pinEncABR, INPUT_PULLUP); pinMode(pinEncBBR, INPUT_PULLUP);

  attachInterrupt(digitalPinToInterrupt(pinEncATL), countPulseTL, RISING);
  attachInterrupt(digitalPinToInterrupt(pinEncATR), countPulseTR, RISING);
  attachInterrupt(digitalPinToInterrupt(pinEncABL), countPulseBL, RISING);
  attachInterrupt(digitalPinToInterrupt(pinEncABR), countPulseBR, RISING);

  Serial.println("Rozpoczynam pomiar za 2 sekundy...");
  delay(2000);

  // --- Start silników na max prędkość ---
  analogWrite(pinPwmTL, 255);
  analogWrite(pinPwmTR, 255);
  analogWrite(pinPwmBL, 255);
  analogWrite(pinPwmBR, 255);

  Serial.println("Pomiar rozpoczęty...");
  unsigned long t0 = millis();

  // --- Zbieranie próbek ---
  for (int i = 0; i < numSamples; i++) {
    unsigned long t = millis() - t0;
    noInterrupts();
    timeStamps[i] = t;
    dataTL[i] = countTL;
    dataTR[i] = countTR;
    dataBL[i] = countBL;
    dataBR[i] = countBR;
    interrupts();
    delay(sampleInterval);
  }

  // --- Zatrzymanie silników ---
  analogWrite(pinPwmTL, 0);
  analogWrite(pinPwmTR, 0);
  analogWrite(pinPwmBL, 0);
  analogWrite(pinPwmBR, 0);
  Serial.println("Pomiar zakonczony.");

  // --- Wypisanie danych ---
  Serial.println("time_ms,TL,TR,BL,BR");
  for (int i = 0; i < numSamples; i++) {
    Serial.print(timeStamps[i]); Serial.print(",");
    Serial.print(dataTL[i]); Serial.print(",");
    Serial.print(dataTR[i]); Serial.print(",");
    Serial.print(dataBL[i]); Serial.print(",");
    Serial.println(dataBR[i]);
  }

  Serial.println("Koniec danych.");
}

void loop() {
  // Nic nie robimy — pomiar już wykonany
}

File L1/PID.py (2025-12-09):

class PID:
    def __init__(self, kp, ki, kd, output_limit=None):
        self.kp = kp
        self.ki = ki
        self.kd = kd
        self.output_limit = output_limit

        self.integral = 0.0
        self.last_error = 0.0
        self.first = True

    def update(self, target, measured, dt):
        error = target - measured

        if self.first:
            derivative = 0.0
            self.first = False
        else:
            derivative = (error - self.last_error) / dt if dt > 0 else 0.0

        self.integral += error * dt
        self.last_error = error

        u = self.kp*error + self.ki*self.integral + self.kd*derivative

        if self.output_limit is not None:
            u = max(-self.output_limit, min(self.output_limit, u))

        return u

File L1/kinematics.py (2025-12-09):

import numpy as np

def omni4_inverse_kinematics(vx, vy, omega, max_wheel_omega_rad_per_s=1.0):
    """
    Compute wheel speeds and directions for 4-wheel omni (mecanum) robot.

    vx, vy  : linear velocities [m/s]
    omega   : angular velocity [rad/s]
    v_max   : maximum linear velocity [m/s]
    omega_max : maximum wheel angular velocity [rad/s]
    """

    # Stałe geometryczne robota
    wheel_diameter_m = 0.08       # średnica koła
    wheel_base_width_m = 0.24     # szerokość robota
    wheel_base_length_m = 0.14    # długość robota

    # Parametry pomocnicze
    r = wheel_diameter_m / 2      # promień koła
    L = wheel_base_length_m / 2   # pół długości robota
    W = wheel_base_width_m / 2    # pół szerokości robota

    # Macierz kinematyki odwrotnej (dla standardowych kół Mecanum)
    M = np.array([
        [ 1, -1, -(L + W)],
        [ 1,  1,  (L + W)],
        [ 1,  1, -(L + W)],
        [ 1, -1,  (L + W)]
    ])

    # Obliczenie prędkości kątowych kół [rad/s]
    wheel_omegas = (1 / r) * M @ np.array([vx, vy, omega])

    # limit handling (scaling all wheels proportionally)
    max_omega = np.max(np.abs(wheel_omegas))
    if max_omega > max_wheel_omega_rad_per_s:
        scale = max_wheel_omega_rad_per_s / max_omega
        wheel_omegas *= scale

    return wheel_omegas

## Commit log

2025-10-21 Accessories
    Accessories, station for camera and battery
    [trzymacz_baterii.FCStd, uchwyt_na_kamere.FCStd]
2025-10-21 Added LL motor driver to the repo, need spend more time working on it
2025-10-28 PI regulator implemented, needs tuning
2025-12-02 Distance Camera FPS fix (#3)
    * Add FPS information to detection output in main function
    * Reduce RealSense stream frame rate to 15 FPS for depth and color streams
2025-12-09 Add distance calculation using bounding box distribution statistics
    * Refactor distance calculation and consolidate .gitignore files
    * Debug_print
    * Adjust depth and color stream configurations for RealSense and update percentile in distance calculation
    * Update distance calculation percentile and clean up debug prints
    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
2025-12-09 Dev dabrz refaktor l1 ll
    * Refactor L1 and LL modularization groundwork
    * Small fixes in L1
    * added feedback
    * added changes in the encoder reading tgread
    * Fixed wrong checksum calculation in the LL
    * Simple feedforward
    * Wheels spinning in the right direction now
    * added PID for wheels
    * fix of the dt
    * tuned the controller XD
    ---------
    [L1.py, LL.ino, PID.py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]
2025-12-16 Bug fixing in L2. New input filtering options and logging added.
